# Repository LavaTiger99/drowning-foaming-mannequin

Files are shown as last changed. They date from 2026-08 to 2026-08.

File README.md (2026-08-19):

# Foaming Drowning Mannequin

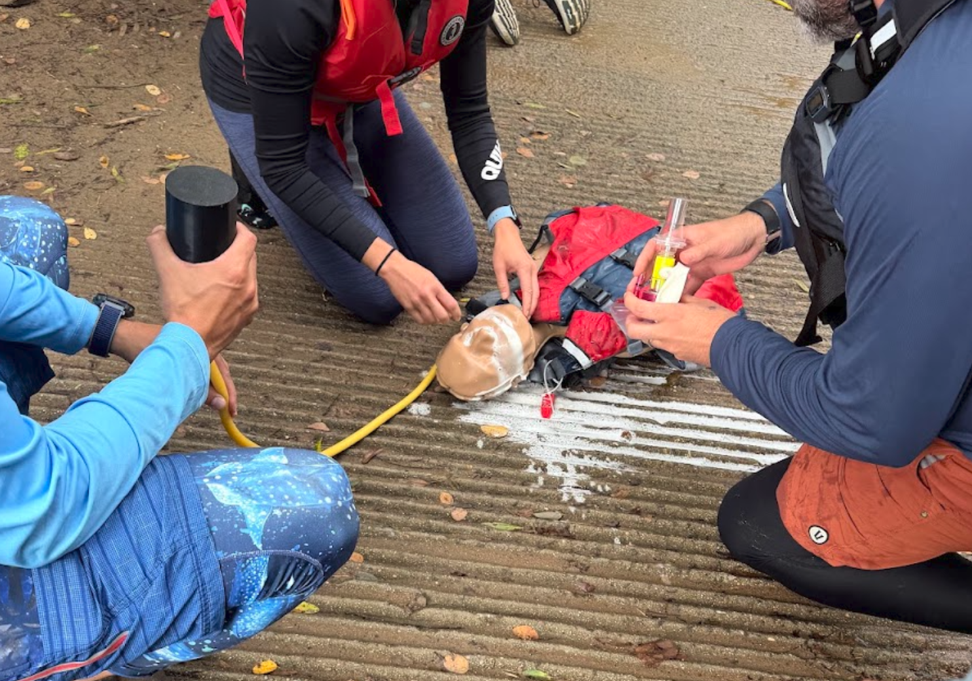
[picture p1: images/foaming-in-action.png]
Foam pouring from a water-rescue manikin’s mouth during a training scenario


*Foam out of the mouth during a water-rescue drill. Invert the mixing bottle when you want it to start.*

A compact, instructor-built training aid that makes foam pour from a Mini Anne’s mouth during a drowning or water-rescue scenario.

It is meant for **medical instructors** who want a simulation of drowning-related surfactant foam at the airway. Mini Anne is inflatable, so the whole kit packs small and travels easily.

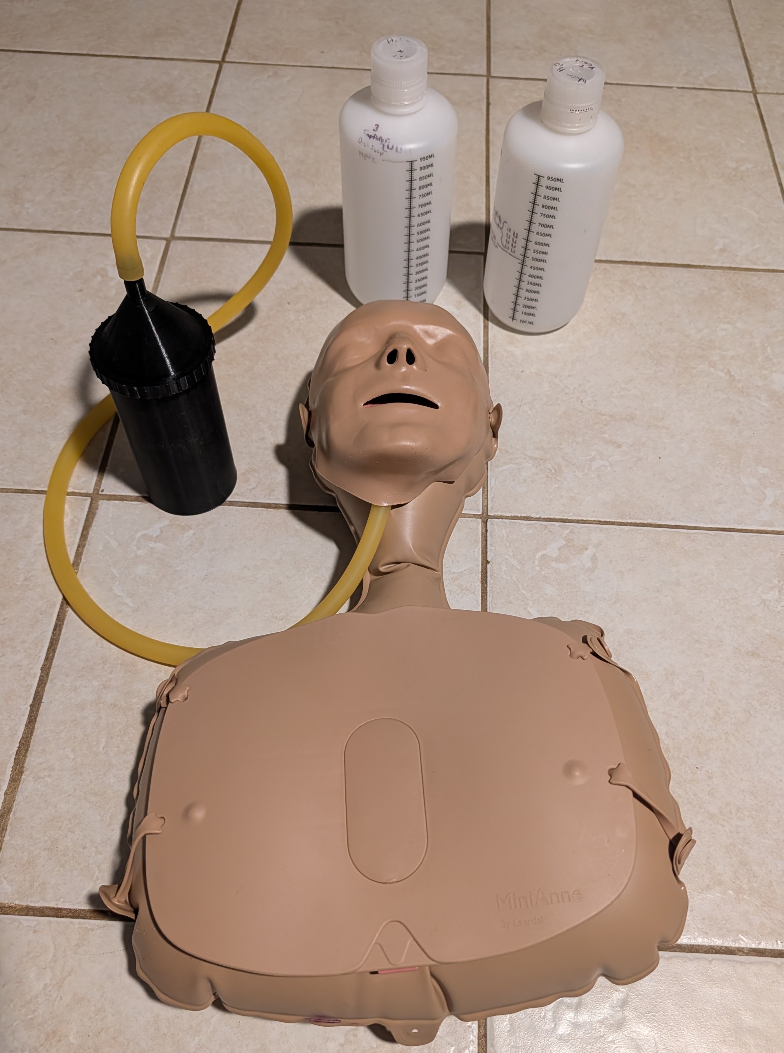
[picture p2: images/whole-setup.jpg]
Full kit: Mini Anne, rubber tubing, mixing bottle, and two marked premix bottles


*Mini Anne, mixing bottle, tubing, and the two premix bottles marked for four rounds. The peroxide bottle is full; the yeast-and-water bottle looks about half full — that is normal.*

> **Training use only.** This is a classroom / scenario prop, not a medical device.

---

## How it works

Two solutions stay separated until you decide the “victim” should foam:

| Chamber | Mix | Role |
| --- | --- | --- |
| **1** | 3% hydrogen peroxide + dish soap | Peroxide supplies oxygen; soap traps it as foam |
| **2** | Room-temperature water\* + dry yeast | Yeast (catalase) triggers the reaction |

Those two mixes live in a **3D-printed mixing bottle** with a divider down the middle. Keep the bottle upright to prime and wait. When the rescue is underway, flip it. Both sides dump into a **funnel-shaped lid**, mix, and foam out through rubber tubing into a **mouthpiece adapter** that pops onto Mini Anne where the lung bag normally sits.

You can leave the tubing **disconnected from the mixing bottle** while the team pulls the manikin out of a pond or lake, then attach the hose when you want foam in the middle of the scenario.

```mermaid
flowchart LR
  C1["Chamber 1<br/>3% H₂O₂ + dish soap"]
  C2["Chamber 2<br/>yeast + room-temp water"]
  Lid["Funnel lid<br/>(mixes when inverted)"]
  Tube["Rubber tubing"]
  Mouth["Mini Anne adapter"]

  C1 --> Lid
  C2 --> Lid
  Lid --> Tube --> Mouth
```

The chemistry is the same classroom reaction as “elephant toothpaste”: yeast breaks hydrogen peroxide into water and oxygen, and the soap turns that oxygen into foam.

\* **Water temperature is the throttle.** Room-temperature / tepid water gives a good, realistic rate. Warmer water speeds the reaction; colder water slows it. Too hot and foam explodes out of the mouth in an unrealistic way. Too cold and it barely activates.

---

## Parts list

### Buy

| Item | Why | Est. price\* | Link |
| --- | --- | --- | --- |
| **Laerdal Mini Anne** (Global Set) | Inflatable adult CPR manikin. Packs down small. The lung bag pops off the mouth from behind; that is where the printed adapter goes. | $42 | <a href="https://www.amazon.com/dp/B0CHSG9MXJ" target="_blank" rel="noopener noreferrer">Amazon</a> |
| **Natural latex tubing** — 3/8 in (10 mm) ID × 9/16 in (14 mm) OD, 1 m | Hose from mixing bottle to mouthpiece. Cut to length. | $9 | <a href="https://www.amazon.com/dp/B093WBLZMP" target="_blank" rel="noopener noreferrer">Amazon</a> |
| **32 oz / 1000 ml HDPE bottles**, pack of 2 | Premix **four rounds** of each solution and mark fill lines on the side. | $15 | <a href="https://www.amazon.com/dp/B0DT6NVHJP" target="_blank" rel="noopener noreferrer">Amazon</a> |
| **Total** | Hardware above. Filament and grocery consumables are extra. | **~$66** | |

\*As of August 2026, Amazon US. Prices move.

### 3D print

Print the **3MF** files in <a href="3d-print-files/" target="_blank" rel="noopener noreferrer"><code>3d-print-files/</code></a>. The matching **Fusion 360** (`.f3d`) files are there if you want to edit the models.

<p align="center">
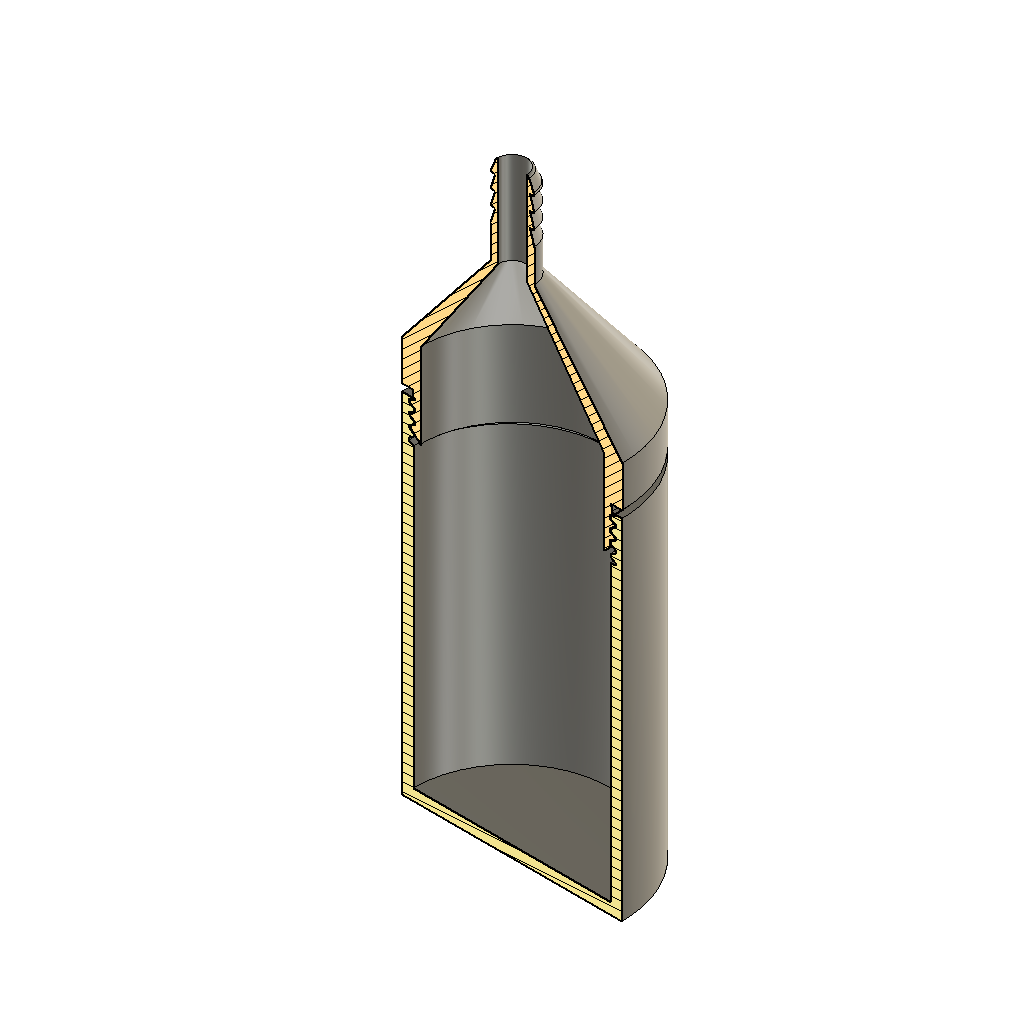
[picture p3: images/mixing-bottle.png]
Cross-section of the mixing bottle and funnel lid
  
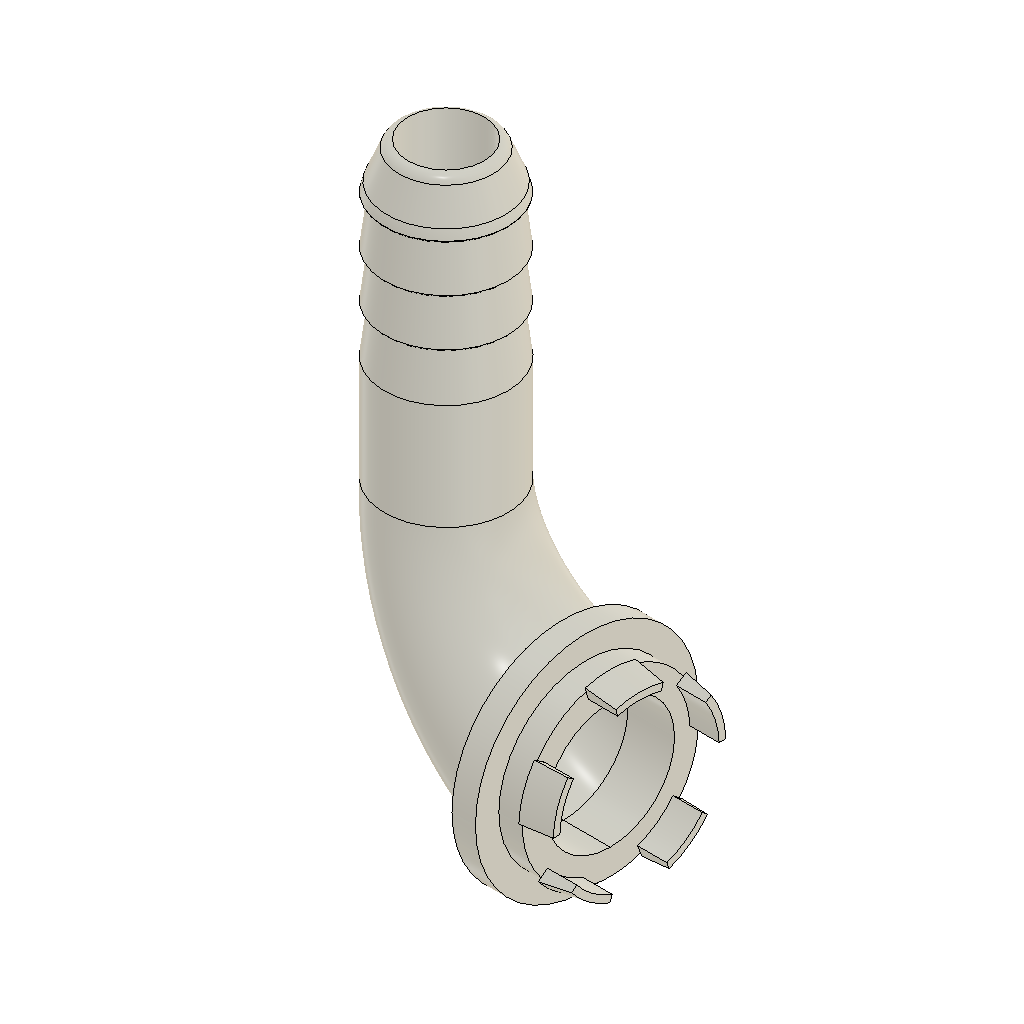
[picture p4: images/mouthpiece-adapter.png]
Mini Anne mouthpiece adapter with hose barb and snap-in tabs
  
</p>

| Part | Print this | Edit this |
| --- | --- | --- |
| **Mixing bottle** (divided jar + funnel lid) | <a href="3d-print-files/Drowning%20Mannequin%20Bottle.3mf" target="_blank" rel="noopener noreferrer">Drowning Mannequin Bottle.3mf</a> | <a href="3d-print-files/Drowning%20Mannequin%20Bottle.f3d" target="_blank" rel="noopener noreferrer">Drowning Mannequin Bottle.f3d</a> |
| **Mouthpiece adapter** | <a href="3d-print-files/Laerdal%20Mini%20Anne%20Mannequin%20Mouth%20Attachment.3mf" target="_blank" rel="noopener noreferrer">Laerdal Mini Anne Mannequin Mouth Attachment.3mf</a> | <a href="3d-print-files/Laerdal%20Mini%20Anne%20Mannequin%20Mouth%20Attachment.f3d" target="_blank" rel="noopener noreferrer">Laerdal Mini Anne Mannequin Mouth Attachment.f3d</a> |

The bottle 3MF contains two bodies: **Jar** (divider down the middle) and **Lid** (funnel that mixes the two sides when you invert it, with a barb for the hose). The mouthpiece pops on where Mini Anne’s lungs were; the other end takes the rubber tubing.

*Other manikins:* if you already have a <a href="https://www.universalmedicalinc.com/simulaids-water-rescue-manikin-adult.html" target="_blank" rel="noopener noreferrer">Simulaids Water Rescue Manikin</a>, there is a separate adapter that plugs into the back of its mouth (<a href="3d-print-files/Simulaids%20Water%20Rescue%20Mannequin%20Foaming%20Adapter.3mf" target="_blank" rel="noopener noreferrer">3MF</a> / <a href="3d-print-files/Simulaids%20Water%20Rescue%20Mannequin%20Foaming%20Adapter.f3z" target="_blank" rel="noopener noreferrer">Fusion</a>). You can also print any custom adapter; the hose end just needs the **same barb** so the 3/8 in (10 mm ID) latex tubing pushes on.

**Print settings:** PLA, **0.4 mm nozzle**. More detail in <a href="3d-print-files/README.md" target="_blank" rel="noopener noreferrer"><code>3d-print-files/README.md</code></a>.

### Consumables (grocery / pharmacy)

- **3% hydrogen peroxide**
- Liquid **dish soap** (the bottle cap is about 1 tablespoon)
- Active dry **yeast** (the kind sold for baking)
- **Room-temperature water\***

---

## Why Mini Anne

Mini Anne is a good fit for a traveling foam kit:

- **Inflatable** — deflates and packs into a small bag
- **Light** — easy to toss into a lake, pool deck, or boat
- **Familiar airway** — students already know the head/chin landmarks
- **Lung mount** — lift the face, pop off the lung bag, pop on the adapter. Nothing is glued to the face.

---

## 3D printing

1. Open the `.3mf` files in your slicer (Bambu Studio, PrusaSlicer, Cura, and most others open 3MF directly).
2. Slice in **PLA** with a **0.4 mm nozzle**.
3. Print the jar with the chambers open upward so the divider is vertical. Print the lid as oriented in the 3MF; add supports if the slicer asks.
4. Check that the 10 mm ID latex tubing is a snug friction fit on both barbs. Latex stretches; warm the tube end in tap water if it is tight.

Suggested starting point:

| Setting | Suggestion |
| --- | --- |
| Material | PLA |
| Nozzle | 0.4 mm |
| Layer height | 0.20 mm |
| Infill | 20–30% (bottle), 40%+ (mouthpiece / barbs) |
| Walls | 3 perimeters |
| Supports | As needed on the funnel lid and any overhanging barbs |

To change geometry, open the `.f3d` files in <a href="https://www.autodesk.com/products/fusion-360/overview" target="_blank" rel="noopener noreferrer">Fusion 360</a>.

---

## Assemble the kit

### 1. Install the mouthpiece

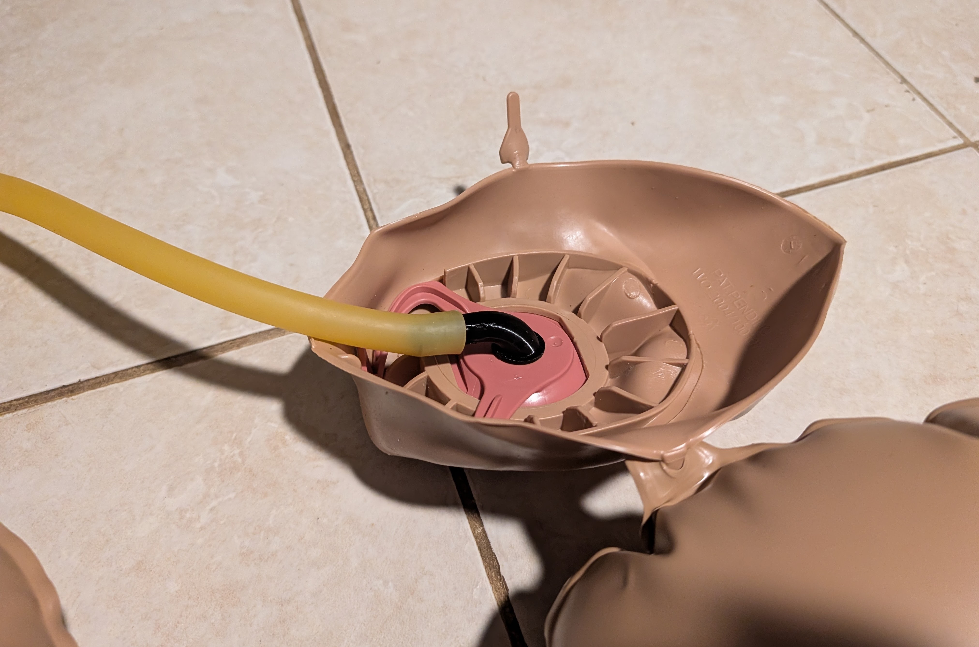
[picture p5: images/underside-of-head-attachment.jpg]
Mouthpiece adapter clicked into the inside of the Mini Anne head, with tubing attached


*Lift the face, pop off the lung bag, and click the adapter in from behind. The tubing pushes onto the barb.*

1. Inflate Mini Anne as usual.
2. **Lift up the face** of the mannequin.
3. **Pop off the lung bag** and detach it from the mannequin.
4. **Pop on the adapter** in that same spot.
5. Push one end of the rubber tubing onto the adapter barb.

Leave the other end of the tubing free if this round starts in the water. You will attach it to the mixing bottle later.

### 2. Mark the premix bottles

The two 32 oz bottles hold **four scenario rounds**. Use a permanent marker on the side so you are not measuring from scratch every class.

**Bottle A — Chamber 1 stock (peroxide + soap)**

- Draw a fill line at **4 cups / 948 ml** for peroxide.
- Label: `+ 4 Tbsp dish soap` (or `+ 4 caps`).

That mix almost fills the 1000 ml bottle. The soap goes in *after* the peroxide line.

**Bottle B — Chamber 2 stock (yeast + water)**

- Draw a fill line at **2 cups / 472 ml** for water.
- Label: `+ 8 Tbsp yeast` (or `+ 8 caps`, about **80 g**).

Bottle A will look **full**. Bottle B will look about **half full**. That is normal — there is less yeast mix than peroxide mix.

Each of these bottle **caps is about one tablespoon**, so you can dose soap and yeast by capfuls if you do not have a measuring spoon on the pool deck.

Premix **Bottle A** ahead of time; peroxide + soap stores fine in a closed bottle. Mix **Bottle B** closer to class so the yeast stays active.

### 3. Charge the mixing bottle

Keep the printed mixer **upright** so the divider does its job.

Pour Chamber 1 mix on one side of the divider and Chamber 2 mix on the other. You only need to fill the bottle to about **3/4 full**, or **an inch from the top**. Match the levels so both sides of the divider are about equal. Do not fill it to the brim — the funnel lid needs headroom when you invert it.

Screw on the funnel lid. The bottle is now **primed**. Set it upright next to the scenario until you want foam.

If you are mixing a single round from scratch (no stock bottles), use the per-round amounts in the recipe below, still stopping at 3/4 full with even levels.

---

## Foam recipe

This kit is built around **3% hydrogen peroxide** and **room-temperature water\***.

### Four rounds (fill the two 32 oz bottles)

#### Chamber 1 — hydrogen peroxide + dish soap

| Ingredient | Amount |
| --- | --- |
| 3% hydrogen peroxide | **4 cups** = 948 ml |
| Liquid dish soap | **4 tablespoons** = 60 ml = **4 bottle caps** |

#### Chamber 2 — yeast + water

| Ingredient | Amount |
| --- | --- |
| Room-temperature water\* | **2 cups** = 472 ml |
| Dry yeast | **8 tablespoons** = 120 ml ≈ **80 g** = **8 bottle caps** |

### One round (mix, then fill the printed bottle)

Mix a small batch of each solution, then pour them into opposite sides of the mixer. Stop when the bottle is about **3/4 full** (an inch from the top) and both sides of the divider are at the same level.

| Chamber | Ingredient | Amount |
| --- | --- | --- |
| 1 | 3% hydrogen peroxide | 1 cup = 237 ml |
| 1 | Liquid dish soap | 1 tablespoon = 15 ml = 1 cap |
| 2 | Room-temperature water\* | ½ cup = 118 ml |
| 2 | Dry yeast | 2 tablespoons ≈ 20 g = 2 caps |

If one side is still low, add more of that same mix until the levels match. You do not need to fill the bottle to the brim.

---

## Running the scenario

### Deck / classroom

1. Manikin is in position with tubing already on the mixer, or with the mixer standing by.
2. Students start the rescue.
3. When you want foam, **invert the mixing bottle**. Both chambers drain, mix in the lid, and foam out the mouth.

### Pond, lake, or pool rescue

The mixer does not have to go in the water.

1. Manikin is in the water with the **mouthpiece and tubing installed**, but the tubing is **off the mixing bottle**.
2. Team does the in-water rescue and gets the manikin to the deck or shore.
3. When you are ready for foam, push the free end of the tubing onto the mixer barb and invert.

---

## Cleanup

Rinse everything with water.

Between multiple runs, **rinse out the mixing bottle with clean water** so leftover reactants do not sit in a chamber and prematurely react on the next fill.

---

## Troubleshooting

| What you see | Likely cause | Fix |
| --- | --- | --- |
| Little or no foam | Water too cold, yeast old, or chambers never mixed | Use tepid water, fresh yeast, and fully invert the bottle |
| Foam explodes out of the mouth | Water too hot | Let the water cool to room temperature |
| Foam starts in the mixer before you flip it | Divider leak, bottle was tilted, or leftover mix from the last run | Keep it upright; rinse the bottle between runs |
| Foam only in the bottle, not the mouth | Kinked hose or adapter not seated | Straighten the tube and reseat the mouthpiece |

---

## Repo layout

```text
.
├── README.md
├── images/                ← photos and CAD previews for this page
└── 3d-print-files/        ← 3MF (print) and Fusion (.f3d / .f3z) models
```

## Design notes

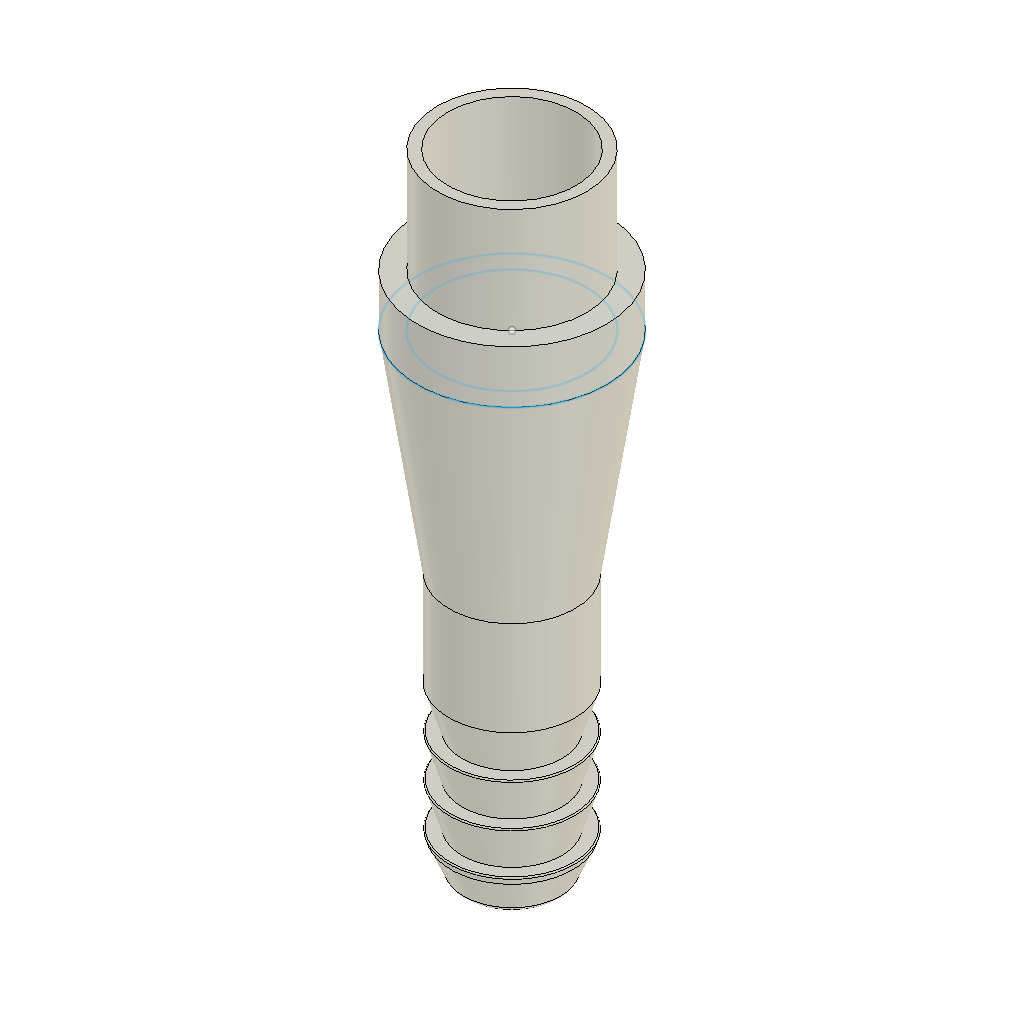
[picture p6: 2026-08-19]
images/simulaids-adapter.png

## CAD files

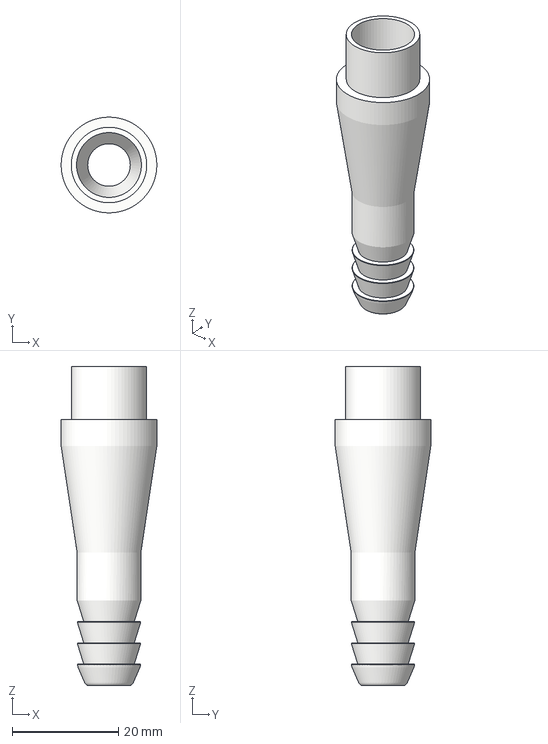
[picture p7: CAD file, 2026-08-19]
3d-print-files/Simulaids Water Rescue Mannequin Foaming Adapter.3mf
18.0 x 18.0 x 60.0 mm

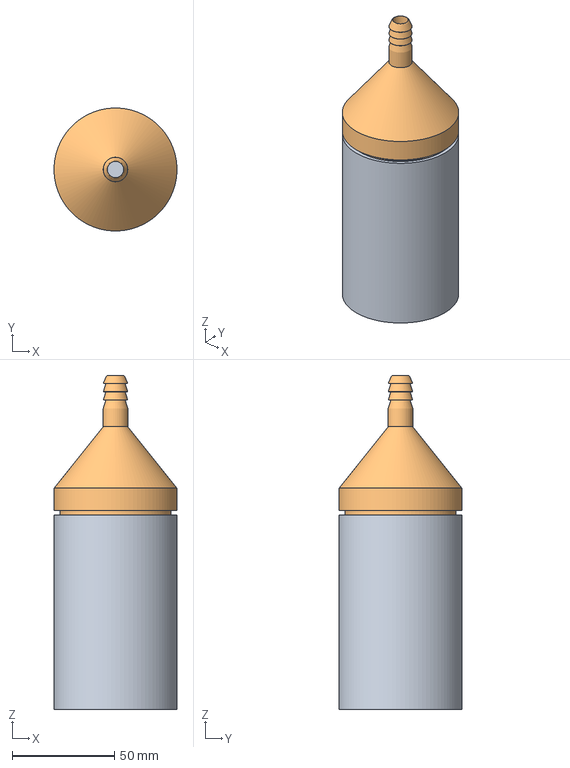
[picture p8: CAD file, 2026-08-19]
3d-print-files/Drowning Mannequin Bottle.3mf
60.0 x 60.0 x 163.0 mm
Jar
Lid

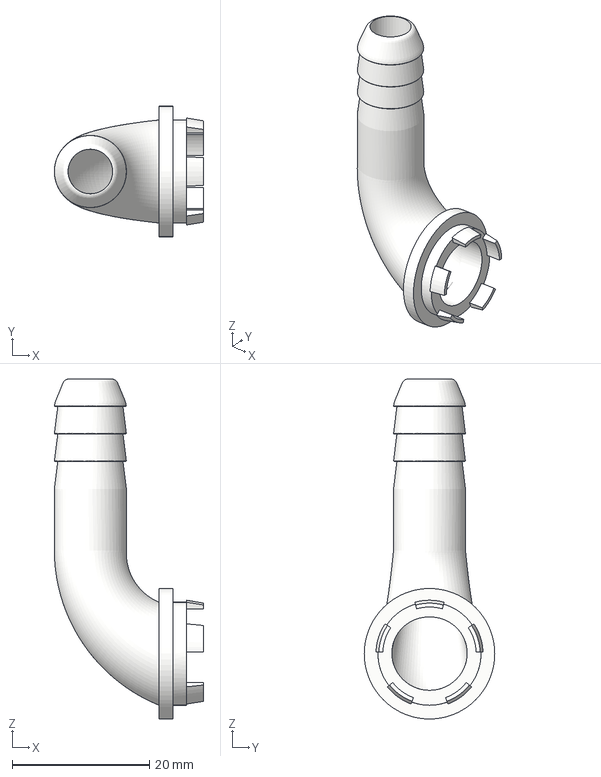
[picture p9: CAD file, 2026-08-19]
3d-print-files/Laerdal Mini Anne Mannequin Mouth Attachment.3mf
21.8 x 19.0 x 49.5 mm

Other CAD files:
3d-print-files/Drowning Mannequin Bottle.f3d
3d-print-files/Laerdal Mini Anne Mannequin Mouth Attachment.f3d
3d-print-files/Simulaids Water Rescue Mannequin Foaming Adapter.f3z

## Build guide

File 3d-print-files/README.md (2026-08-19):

# 3D print files

**Print** the `.3mf` files. **Edit** the `.f3d` files in Fusion 360.

| Part | 3MF (print) | Fusion (edit) |
| --- | --- | --- |
| Mixing bottle — divided **Jar** + funnel **Lid** | <a href="Drowning%20Mannequin%20Bottle.3mf" target="_blank" rel="noopener noreferrer">Drowning Mannequin Bottle.3mf</a> | <a href="Drowning%20Mannequin%20Bottle.f3d" target="_blank" rel="noopener noreferrer">Drowning Mannequin Bottle.f3d</a> |
| Mini Anne mouthpiece — pops on in place of the lung bag | <a href="Laerdal%20Mini%20Anne%20Mannequin%20Mouth%20Attachment.3mf" target="_blank" rel="noopener noreferrer">Laerdal Mini Anne Mannequin Mouth Attachment.3mf</a> | <a href="Laerdal%20Mini%20Anne%20Mannequin%20Mouth%20Attachment.f3d" target="_blank" rel="noopener noreferrer">Laerdal Mini Anne Mannequin Mouth Attachment.f3d</a> |

*Other manikins:* <a href="https://www.universalmedicalinc.com/simulaids-water-rescue-manikin-adult.html" target="_blank" rel="noopener noreferrer">Simulaids Water Rescue Manikin</a> adapter that plugs into the back of the mouth — <a href="Simulaids%20Water%20Rescue%20Mannequin%20Foaming%20Adapter.3mf" target="_blank" rel="noopener noreferrer">3MF</a> / <a href="Simulaids%20Water%20Rescue%20Mannequin%20Foaming%20Adapter.f3z" target="_blank" rel="noopener noreferrer">Fusion <code>.f3z</code></a>. A custom adapter is fine too if the hose end uses the same barb as the mixing-bottle lid (3/8 in / 10 mm ID latex tubing).

## Recommended print settings

Designed around **PLA** and a **0.4 mm nozzle**.

| Setting | Starting point |
| --- | --- |
| Material | PLA |
| Nozzle | 0.4 mm |
| Layer height | 0.20 mm |
| Infill | 20–30% for the bottle; 40% or more for the mouthpiece and hose barbs |
| Perimeters | 3 |
| Supports | As needed on the funnel lid and any overhanging barb |
| Bed | Standard PLA (glue stick or textured PEI) |

Print the jar with the chambers open upward so the divider is vertical. After printing, test-fit:

1. Divider actually separates the two chambers when the bottle is upright.
2. Lid seals well enough that you can invert the bottle without a geyser around the threads.
3. 10 mm ID latex tubing pushes onto both barbs and stays put.

A light chamfer with a hobby knife on the barb helps the hose start on.

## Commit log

2026-08-19 Add instructional README for the foaming drowning mannequin (#1)
    * Add instructional README and 3D print folder for the foaming mannequin kit
    Document parts, Mini Anne conversion, four-round premix bottles, foam recipe, scenario use (including disconnected hose for water rescues), cleanup, and safety. Leave 3d-print-files/ ready for the STLs.
    * Replace placeholder readme.md with the instructional README.md
    GitHub renders README.md at the repo root; the old placeholder is no longer needed.
    ---------
    C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
2026-08-19 3d print files
    [Drowning Mannequin Bottle.3mf, Drowning Mannequin Bottle.f3d, Laerdal Mini Anne Mannequin Mouth Attachment.3mf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]
2026-08-19 Link 3D print files and tighten the build instructions (#2)
    * Link 3D print files and update the foam recipe and install steps
    Point the README at the 3MF and Fusion models, embed CAD previews, switch the recipe to 3% peroxide and room-temperature water with a temperature note, simplify mouthpiece install and cleanup, and drop food coloring.
    * Note filling the mixing bottle to 3/4 full with even chamber levels
    Stop about an inch from the top instead of filling to the brim, and keep both sides of the divider at the same height.
    ---------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
2026-08-19 Embed the full-kit and mouth-attachment photos in the README
    Rename the two photos to kebab-case, put the assembled kit at the top of the page, and show the adapter seated inside the Mini Anne head in the install steps.
2026-08-19 Add Simulaids water-rescue mouth adapter as an alternate (#4)
    * Embed the full-kit and mouth-attachment photos in the README
    * Add Simulaids water-rescue adapter as an alternate mouthpiece
    Link the new 3MF and Fusion archive, note that any custom adapter is fine if it uses the same hose barb, and keep Mini Anne as the compact default.
    * Put the foaming-in-action photo at the top of the README
    Rena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
2026-08-19 Keep Mini Anne as the core kit and add buy-list prices (#5)
    * Keep Mini Anne as the core kit and add August 2026 buy prices
    Move Simulaids off the parts table into a short mouthpiece note, add estimated Amazon prices with a total, and mention that the half-full yeast bottle is normal.
    * Open README and print-file links in a new tab
    GitHub markdown links cannot set a target, so product and file links are HTML anchors with target=_blank.
    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
2026-08-19 Specify larger mixer chamber for peroxide and smaller for yeast
    Keep fill heights even at about 3/4 full; the larger side simply holds more liquid.
2026-08-24 Replace mixing bottle CAD with Drowning Sim Bottle files (#7)
    Swap the outdated Drowning Mannequin Bottle 3MF and Fusion models for the current Drowning Sim Bottle files, and point the README links at the new names.
